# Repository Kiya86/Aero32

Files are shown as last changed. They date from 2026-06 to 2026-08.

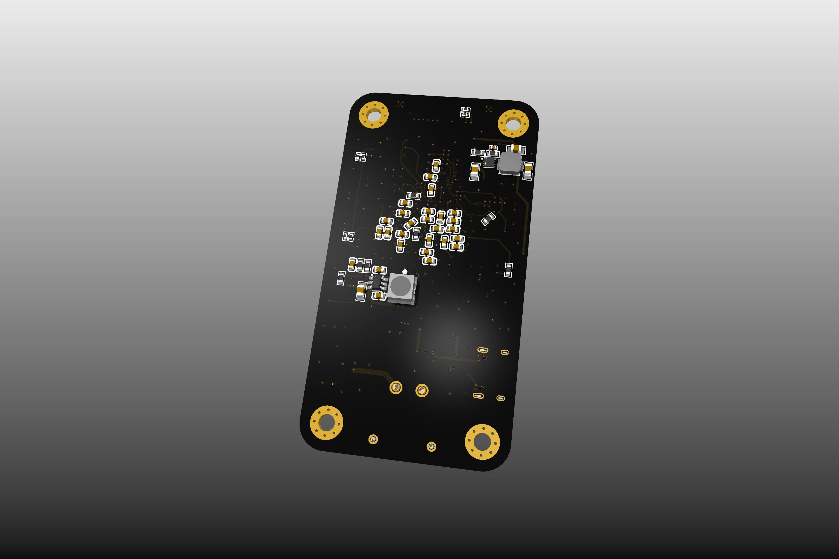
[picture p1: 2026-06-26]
Photos/BoardRender2.jpg

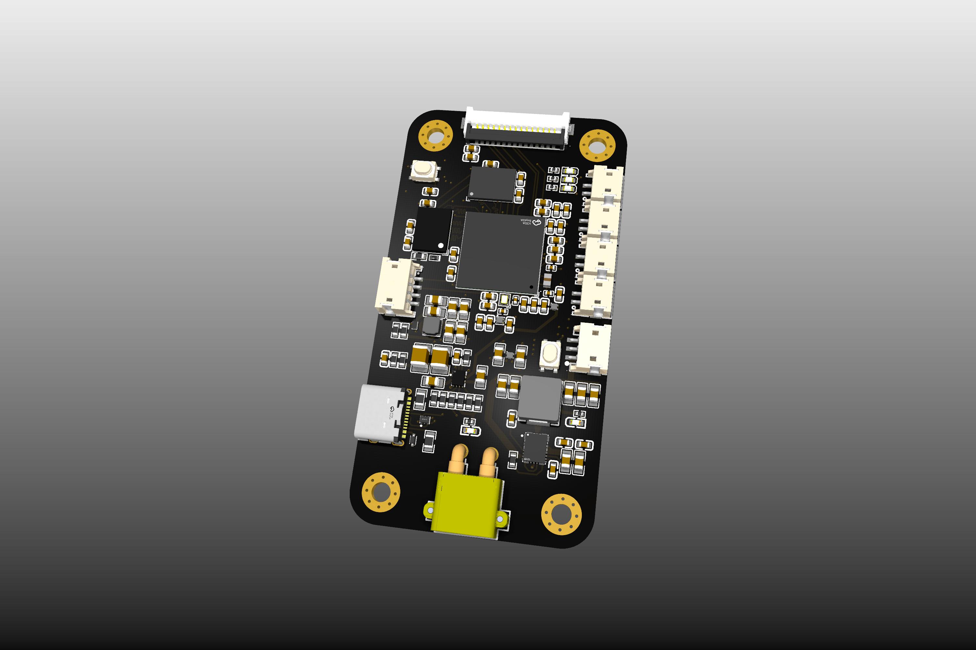
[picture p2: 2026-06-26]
Photos/BoardRender1.jpg

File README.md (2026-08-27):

# Aero32

MainRender1
BoardRender1

<h4 align="center">
A custom STM32N6-based AI vision module!
</h4>

<div align="center">





</div>

<p align="center">
  <a href="#key-features">Key Features</a> •
  <a href="#purpose">Purpose</a> •
  <a href="#pcb">PCB</a> •
  <a href="#main-components">Main Components</a> •
  <a href="#communication-interfaces">Communication Interfaces</a> •
  <a href="#power-architecture">Power System</a> •
  <a href="#bom">BOM</a> 
</p>

## Key Features

- **STM32N657X0H3Q** - Neural-ART accelerator that is used alongside the STM32N6 MCU
- **15-Pin CSI FPC Connector** - Camera sensor interface
- **MT35XU256ABA1G12** - 256 Mbit Octal SPI NOR Flash for either firmware or data 
- **IS66WVO32M8DALL** - 256 Mbit PSRAM for working memory
- **2× UART Ports** - Serial breakout headers
- **2× I2C Ports** - Two-wire serial communication breakout headers
- **1× SPI Port** - High-speed peripheral interface breakout
- **48 MHz & 32.768 kHz Crystals** - System clock and low power RTC
- **XT30 Battery Input** - 3S–4S LiPo input
- **5× Status LEDs** - 3 green + 2 red for power and debug feedback
- **Input OR** - TPS2121 power multiplexer for safe dual-source power switching

## Purpose

Aero32 is a small and compact AI vision board designed to serve as a node for drones or other flight hardware. The board offloads computer vision and processing from the external processing, communicating the results over UART, I2C, or SPI.

The STM32N6's Neural Processing Unit (NPU) allows anomaly detection, human recognition, and other advanced recognition directly on the board without AI hardware or wifi.

## PCB

Designed in **KiCad** and manufactured through **JLCPCB** (soon). The board uses a **6-layer PCB stackup** to allow for a reduction of EMI and signal interference. 

### Schematic

Aero32-1

## Main Components

| Category | Component | Description |
|---|---|---|
| Microcontroller | STM32N657X0H3Q | STM32N6 with NPU |
| NOR Flash | MT35XU256ABA1G12-0AUT | 256 Mbit Octal SPI Flash (Micron) |
| PSRAM | IS66WVO32M8DALL-200BLI | 256 Mbit Pseudo-SRAM (ISSI) |
| Camera Connector | XF3M(1)-1515-1B | 15-Pin 1mm Pitch FPC (Omron) |
| Main Buck Regulator | LM61495Q5RPHRQ1 | 3–36V 10A Automotive Buck (TI) |
| Aux Buck (3A) | AP3441LSHE-7B | 2.7–5.5V 3A Adjustable Buck |
| Aux Buck (3A) | TPS62088YFPR | 2.4–5.5V 3A Adjustable Buck (TI) |
| Fixed 3.3V Buck | TPS560430X3FDBVR | 4–36V 600mA 3.3V Fixed Buck (TI) |
| 1.8V LDO (×2) | ETA5055V180DD1E | 1.8V 500mA LDO |
| 3.3V LDO | ETA5055V330DD1E | 3.3V 500mA LDO |
| Power Mux | TPS2121RUXR | ORing Power Multiplexer (TI) |
| USB ESD | TPD2E001DRYR | 2-Channel USB ESD Protection (TI) |
| USB Connector | HC-TYPE-C-16P-01A-G | USB Type-C 16P 3A Female |
| Power Input | XT30PW-M | XT30 Male 15A Connector |
| System Crystal | SX0B48.000F0810F30 | 48 MHz ±10ppm Crystal |
| RTC Crystal | NX2012SA 32.768K | 32.768 kHz ±20ppm Crystal |
| Boot / Reset | K2-1808SN-A4SW | SPST Tactile Switch (×2) |
| Status LEDs | KT-0603G / KT-0603R | Green (×3) / Red (×2) 0603 LEDs |
| TVS Diode | LESD5D5.0CT1G | 150W Bidirectional TVS 5V |

## Communication Interfaces

### UART (×2)
Two independent UART breakout ports via 2-pin JST ZH 1.5mm connectors.

### I2C (×2)
Two I2C ports broken out via JST ZH 1.5mm connectors.

### SPI (×1)
One SPI port available for high-speed peripheral communication.

### Camera (CSI)
A 15-pin 1mm pitch FPC connector (Omron XF3M) provides the camera sensor interface.

## Power Architecture

Aero32 supports dual power inputs (USB-C and XT30 battery) with automatic source switching via the TPS2121 power mux.

## BOM

The full Bill of Materials is available in [`Aero32_BOM.csv`](./PCB/Aero32_BOM.csv), formatted for direct JLCPCB assembly upload.

JLCPCB Quote


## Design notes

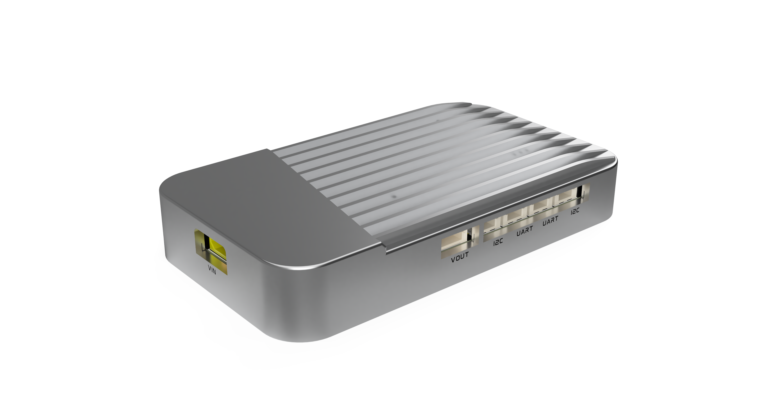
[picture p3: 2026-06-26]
Photos/MainRender3.png

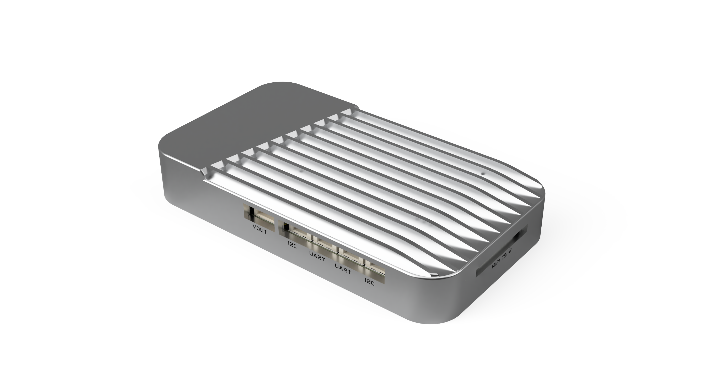
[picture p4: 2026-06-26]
Photos/MainRender1.png

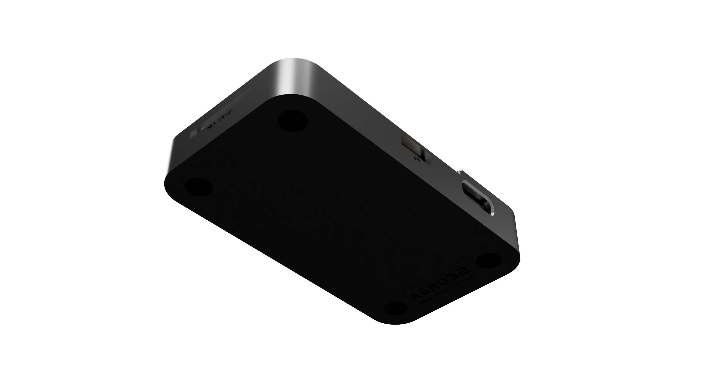
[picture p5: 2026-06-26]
Photos/MainRender2.png

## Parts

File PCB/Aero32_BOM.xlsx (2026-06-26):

Comment | Designator | Footprint | JLCPCB Part #（optional）
100nF | C19, C27, C29, C36, C37, C44, C46, C53, C54, C55, C57, C58, C60, C61, C62, C64, C65, C67, C68, C69, C71, C73, C74, C77, C78, C79, C81, C82, C83, C84, C86, C87, C88, C90, C91, C92 | C0603 | C45000
1uF | C1, C3, C10, C13, C14, C16, C17, C35, C48, C56, C59, C63, C66, C70, C72, C75, C76, C80, C85, C89, C93, C94 | C0603 | C1592
22uF | C18, C21, C22, C23, C25, C26, C30, C31, C34, C38, C40, C43, C47 | C0805 | C76634
10uF | C2, C4, C5, C6, C9, C11, C12, C15 | C0805 | C440198
470nF | C7, C8 | C0603 | C513577
47uF | C24, C28 | C1210 | C84494
8.2pF | C49, C52 | C0402 | C260529
2.2pF | C50, C51 | C0402 | C88887
22pF | C33 | C0402 | C1555
4.7uF | C41 | C0603 | C1705
2.2uF | C45 | C0603 | C1607
10kΩ | R2, R4, R6, R34 | R0603 | C25804
10kΩ | R14, R16, R27, R30 | R0603 | C25804
1.5kΩ | R21, R22, R24, R25 | R0402 | C25867
100kΩ | R12, R13, R37 | R0603 | C14675
68Ω | R31, R33, R36 | R0402 | C25178
47kΩ | R3, R5 | R0603 | C25819
5.1kΩ | R7, R8 | R0805 | C269748
2.2kΩ | R23, R26 | R0402 | C25879
200Ω | R28, R29 | R0603 | C8218
1kΩ | R32, R35 | R0402 | C11702
27kΩ | R1 | R0603 | C22967
56.2kΩ | R9 | R0603 | C23080
115kΩ | R10 | R0603 | C22783
18.7kΩ | R11 | R0603 | C22893
150kΩ | R15 | R0603 | C22807
91kΩ | R19 | R0603 | C23265
20kΩ | R20 | R0603 | C4184
240nH | L1 | IND-SMD_L3.0-W3.0_MAI3015S | C520265
2.7uH | L2 | IND-SMD_DH0630H-1R5M | C41407066
2.2uH | L4 | IND-SMD_L4.5-W4.1_GSSM0420 | C22463806
12uH | L5 | IND-SMD_L4.8-W4.8 | C22385343
TVS | D1 | SOD-523_L1.2-W0.8-LS1.6-BI | C383211
Diode | D2 | DSN2_L1.0-W0.6-RD | C604339
ETA5055V180DD1E | U1, U3 | DFN-4_L1.0-W1.0-P0.65-BL-EP | C5776774
ETA5055V330DD1E | U2 | XDFN-4_L1.0-W1.0-P0.65-BL-EP | C22466949
TPS62088YFPR | U4 | DSBGA-6_L0.8-W1.2-P0.40-R3-C2-TL | C575572
TPD2E001DRYR | U5 | SON-6_L1.5-W1.0-P0.50-BL | C379992
TPS2121RUXR | U6 | VQFN-HR-12_L2.5-W2.0-P0.50-BL | C485916
LM61495Q5RPHRQ1_C3188409 | U7 | VQFN-16_L4.5-W3.5-P0.50-TL_TI_RPH | C3188409
AP3441LSHE-7B | U9 | DFN-8_L2.0-W2.0-P0.50-BL-EP1.7 | C2072094
TPS560430X3FDBVR | U10 | SOT-23-6_L2.9-W1.6-P0.95-LS2.8-BR | C2071721
STM32N657X0H3Q | U11 | BGA-264_L14.0-W14.0-STM32N657X0H3Q | C42418080
MT35XU256ABA1G12-0AUT | U12 | T-PBGA-24_L8.0-W6.0-P1.00-TL_MICRON_12 | C7235747
IS66WVO32M8DALL-200BLI | U13 | TFBGA-24_L8.0-W6.0-P1.00-TL_MX25UW25645GXDI00 | C17535354
32.768kHz | X1 | XTAL_NX2012SA_NDK | C500343
48MHz | X2 | CRYSTAL-SMD_4P-L1.6-W1.2-BL | C7301928
K2-1808SN-A4SW | SW1, SW2 | KEY-SMD_4P-L4.2-W3.2-P2.20-LS5.1-TL | C92589
JST | CN2, CN3, CN4, CN5 | CONN-SMD_S2B-ZR-SM4A | C265329
KT-0603G | LED1, LED3, LED5 | LED0603-RD | C12624
KT-0603R | LED2, LED4 | LED-SMD_L1.6-W0.8-R-RD | C2286
XT30PW-M | CN1 | CONN-TH_XT30PW-M | C431092
JST | CN6 | CONN-TH_S3B-ZR-SM4A-TF-LF-SN | C72591
JST | CN7 | CONN-SMD_4P-P1.50_S4B-ZR-SM4A-TF-LF-SN | C485354
XF3M | FPC1 | FPC-SMD_XF3M-1-1515-1B | C6036307
HC-TYPE-C-16P-01A-G | USB1 | USB-C-SMD_G-SWITCH_GT-USB-7010EN | C2997435

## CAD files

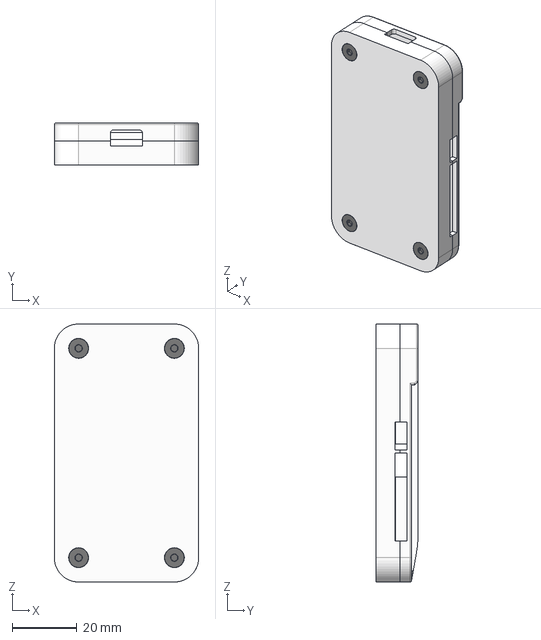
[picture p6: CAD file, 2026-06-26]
CAD/Aero32 - Housing.step
44.5 x 13.0 x 79.5 mm

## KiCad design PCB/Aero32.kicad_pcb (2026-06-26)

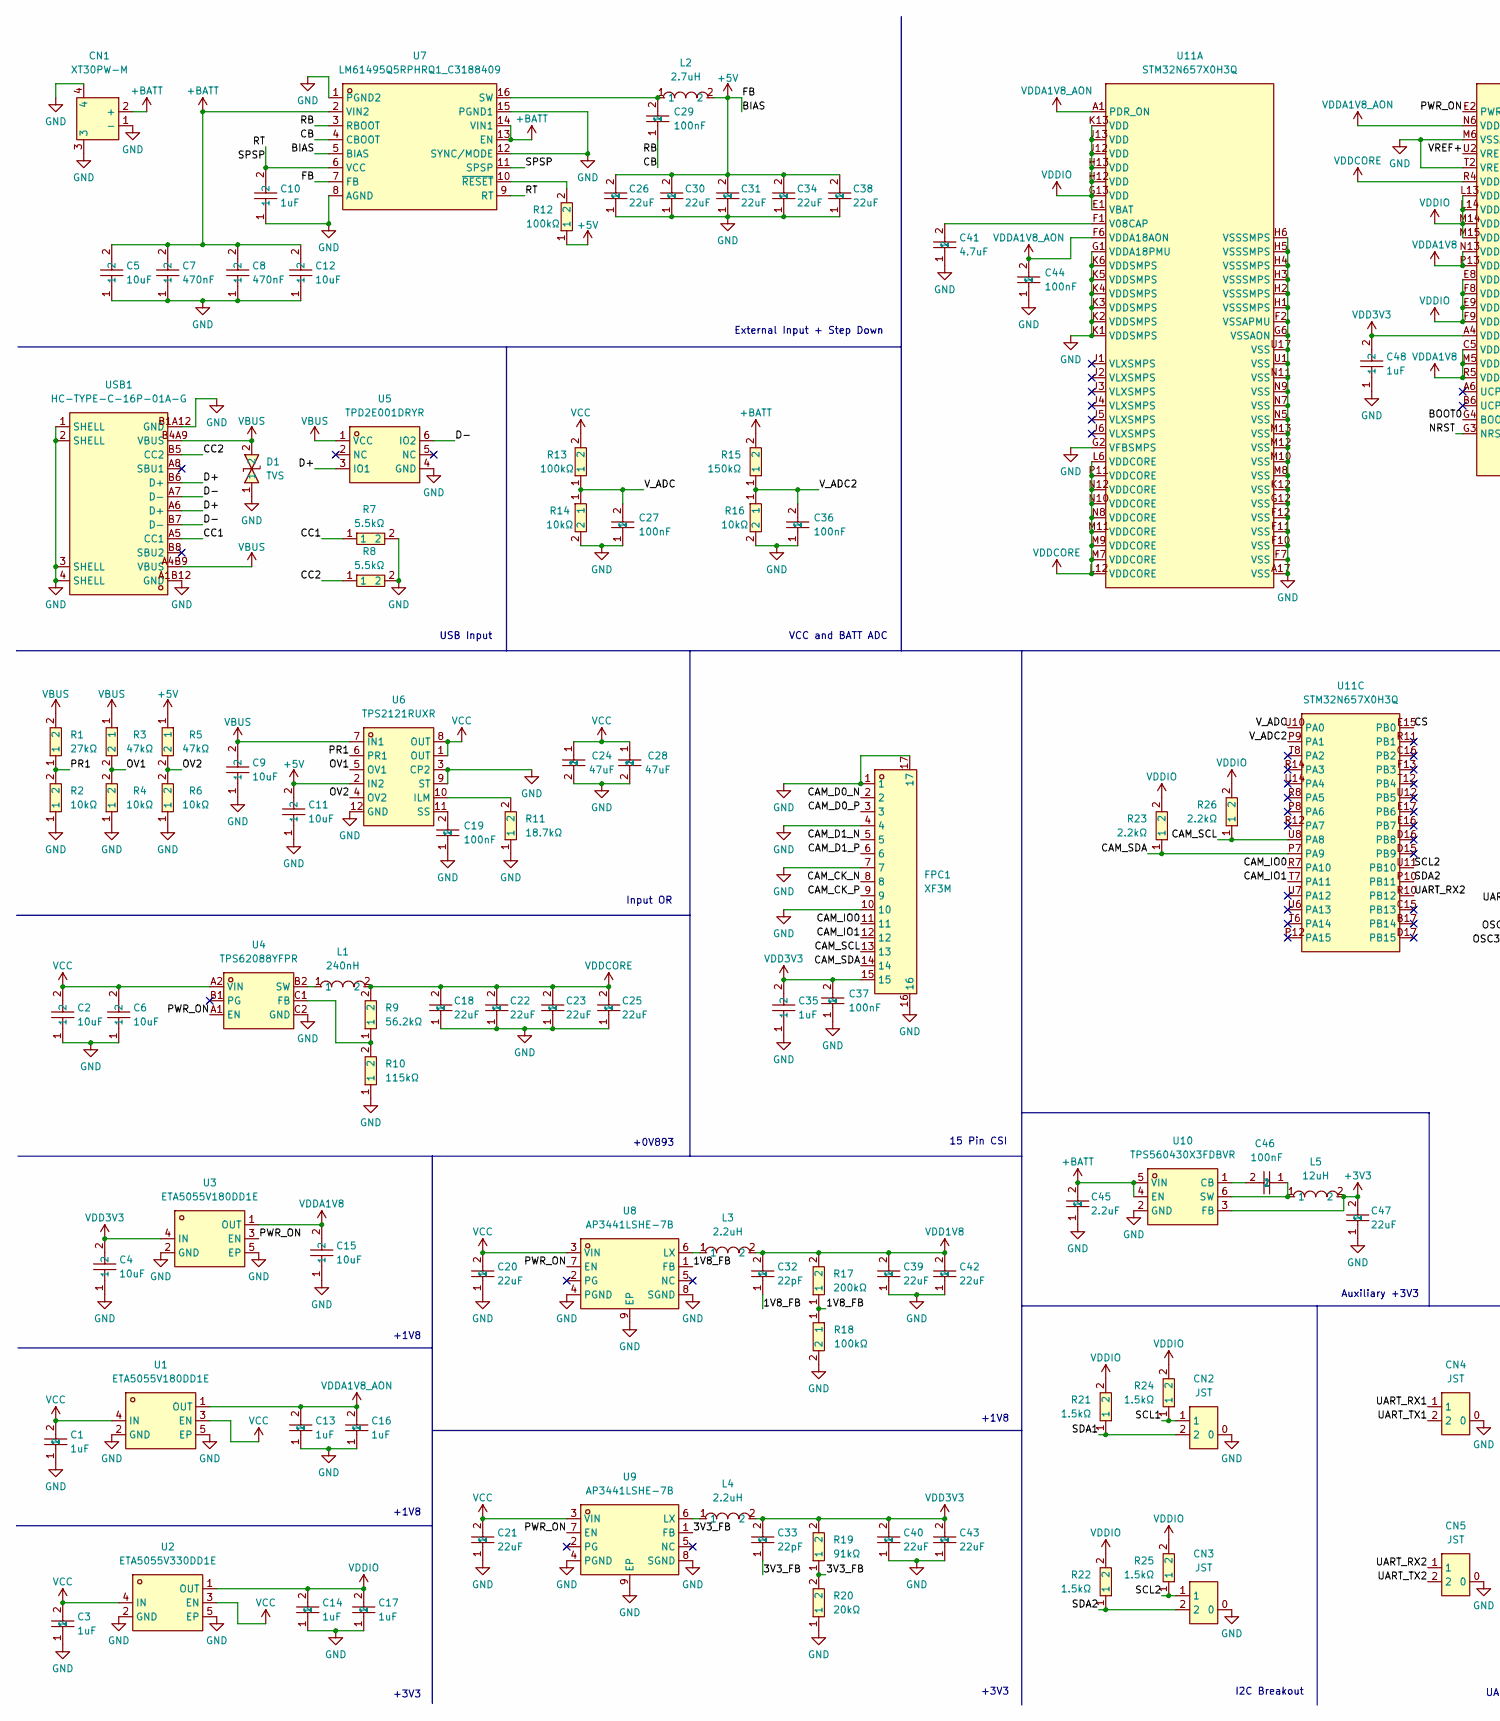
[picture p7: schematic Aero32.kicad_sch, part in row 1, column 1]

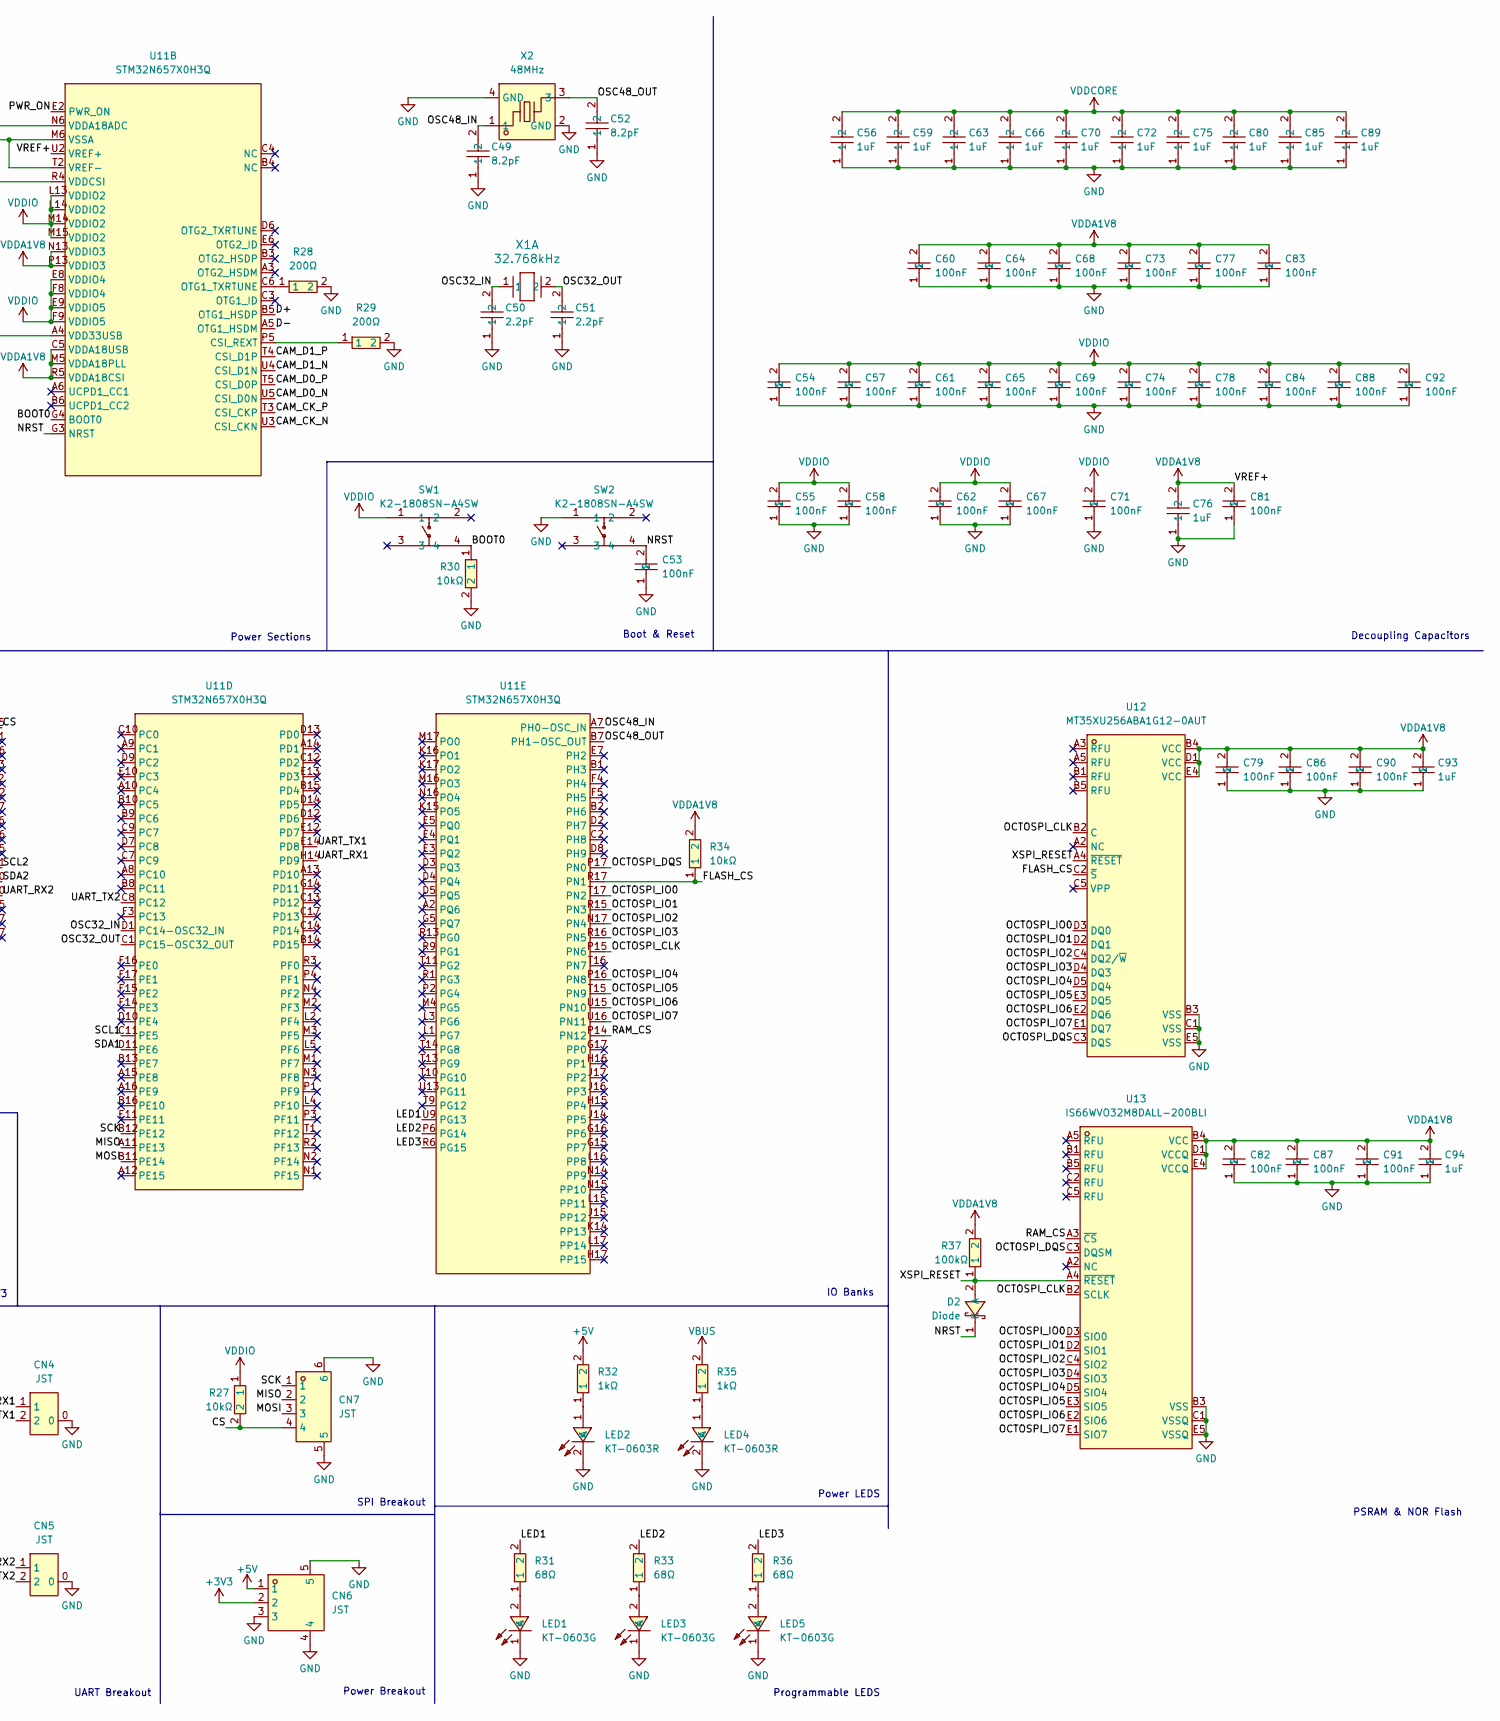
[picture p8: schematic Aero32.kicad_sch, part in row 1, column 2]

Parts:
C1, C3, C13, C14, C16, C17, C93, C94: 1uF; C0603; MPN CL10A105KO8NNNC; LCSC Part C1592
C2, C4, C5, C6, C9, C11, C12, C15: 10uF; C0805; MPN GRM21BR61H106KE43L; LCSC Part C440198
C7, C8: 470nF; C0603; MPN CC0603KRX7R9BB474; LCSC Part C513577
C10, C35, C48, C56, C59, C63, C66, C70, C72, C75, C76, C80, C85, C89: 1uF; C0603; MPN CL10A105KB8NNNC; LCSC Part C15849
C18, C20, C21, C22, C23, C25, C26, C30, C31, C34, C38, C39, C40, C42, C43, C47: 22uF; C0805; MPN C2012X5R1A226KT000N; LCSC Part C76634
C19, C27, C29, C36, C37, C44, C46, C53, C54, C55, C57, C58, C60, C61, C62, C64, C65, C67, C68, C69, C71, C73, C74, C77, C78, C79, C81, C82, C83, C84, C86, C87, C88, C90, C91, C92: 100nF; C0603; MPN GRM188R71C104KA01D; LCSC Part C45000
C24, C28: 47uF; C1210; MPN GRM32ER71A476KE15L; LCSC Part C84494
C32, C33: 22pF; C0402; MPN 0402CG220J500NT; LCSC Part C1555
C41: 4.7uF; C0603; MPN CL10A475KP8NNNC; LCSC Part C1705
C45: 2.2uF; C0603; MPN CL10A225KP8NNNC; LCSC Part C1607
C49, C52: 8.2pF; C0402; MPN CC0402CRNPO9BN8R2; LCSC Part C260529
C50, C51: 2.2pF; C0402; MPN GJM1555C1H2R2WB01D; LCSC Part C88887
CN1: XT30PW-M; CONN-TH_XT30PW-M; MPN XT30PW-M30.G.Y; LCSC Part C431092
CN2, CN3, CN4, CN5: JST; CONN-SMD_S2B-ZR-SM4A; MPN S2B-ZR-SM4A-TF(LF)(SN); LCSC Part C265329
CN6: JST; CONN-TH_S3B-ZR-SM4A-TF-LF-SN; MPN S3B-ZR-SM4A-TF(LF)(SN); LCSC Part C72591
CN7: JST; CONN-SMD_4P-P1.50_S4B-ZR-SM4A-TF-LF-SN; MPN S4B-ZR-SM4A-TF(LF)(SN); LCSC Part C485354
D1: TVS; SOD-523_L1.2-W0.8-LS1.6-BI; MPN LESD5D5.0CT1G; LCSC Part C383211
D2: Diode; DSN2_L1.0-W0.6-RD; MPN NSR05F30NXT5G; LCSC Part C604339
FPC1: XF3M; FPC-SMD_XF3M-1-1515-1B; MPN XF3M(1)-1515-1B; LCSC Part C6036307
L1: 240nH; IND-SMD_L3.0-W3.0_MAI3015S; MPN MAI3015S-R24MT; LCSC Part C520265
L2: 2.7uH; IND-SMD_DH0630H-1R5M; MPN DH0630H-2R7M; LCSC Part C41407066
L3, L4: 2.2uH; IND-SMD_L4.5-W4.1_GSSM0420; MPN SL0420-2R2M; LCSC Part C22463806
L5: 12uH; IND-SMD_L4.8-W4.8; MPN LPS5030-123MRC; LCSC Part C22385343
LED1, LED3, LED5: KT-0603G; LED0603-RD; MPN KT-0603G; LCSC Part C12624
LED2, LED4: KT-0603R; LED-SMD_L1.6-W0.8-R-RD; MPN KT-0603R; LCSC Part C2286
R1: 27kΩ; R0603; MPN 0603WAF2702T5E; LCSC Part C22967
R2, R4, R6, R34: 10kΩ; R0603; MPN 0603WAF1002T5E; LCSC Part C25804
R3, R5: 47kΩ; R0603; MPN 0603WAF4702T5E; LCSC Part C25819
R7, R8: 5.5kΩ; R0805; MPN RMC08055.1K1%N; LCSC Part C269748
R9: 56.2kΩ; R0603; MPN 0603WAF5622T5E; LCSC Part C23080
R10: 115kΩ; R0603; MPN 0603WAF1153T5E; LCSC Part C22783
R11: 18.7kΩ; R0603; MPN 0603WAF1872T5E; LCSC Part C22893
R12, R13, R18, R37: 100kΩ; R0603; MPN RC0603FR-07100KL; LCSC Part C14675
R14, R16, R27, R30: 10kΩ; R0603; MPN 0603WAJ0103T5E; LCSC Part C15401
R15: 150kΩ; R0603; MPN 0603WAF1503T5E; LCSC Part C22807
R17: 200kΩ; R0603; MPN 0603WAF2003T5E; LCSC Part C25811
R19: 91kΩ; R0603; MPN 0603WAF9102T5E; LCSC Part C23265
R20: 20kΩ; R0603; MPN 0603WAF2002T5E; LCSC Part C4184
R21, R22, R24, R25: 1.5kΩ; R0402; MPN 0402WGF1501TCE; LCSC Part C25867
R23, R26: 2.2kΩ; R0402; MPN 0402WGF2201TCE; LCSC Part C25879
R28, R29: 200Ω; R0603; MPN 0603WAF2000T5E; LCSC Part C8218
R31, R33, R36: 68Ω; R0402; MPN 0402WGJ0680TCE; LCSC Part C25178
R32, R35: 1kΩ; R0402; MPN 0402WGF1001TCE; LCSC Part C11702
SW1, SW2: K2-1808SN-A4SW; KEY-SMD_4P-L4.2-W3.2-P2.20-LS5.1-TL; MPN K2-1808SN-A4SW-01; LCSC Part C92589
U1, U3: ETA5055V180DD1E; DFN-4_L1.0-W1.0-P0.65-BL-EP; MPN ETA5055V180DD1E; LCSC Part C5776774
U2: ETA5055V330DD1E; XDFN-4_L1.0-W1.0-P0.65-BL-EP; MPN ETA5055V330DD1E; LCSC Part C22466949
U4: TPS62088YFPR; DSBGA-6_L0.8-W1.2-P0.40-R3-C2-TL; MPN TPS62088YFPR; LCSC Part C575572
U5: TPD2E001DRYR; SON-6_L1.5-W1.0-P0.50-BL; MPN TPD2E001DRYR; LCSC Part C379992
U6: TPS2121RUXR; VQFN-HR-12_L2.5-W2.0-P0.50-BL; MPN TPS2121RUXR; LCSC Part C485916
U7: LM61495Q5RPHRQ1_C3188409; VQFN-16_L4.5-W3.5-P0.50-TL_TI_RPH; MPN LM61495Q5RPHRQ1; LCSC Part C3188409
U8, U9: AP3441LSHE-7B; DFN-8_L2.0-W2.0-P0.50-BL-EP1.7; MPN AP3441LSHE-7B; LCSC Part C2072094
U10: TPS560430X3FDBVR; SOT-23-6_L2.9-W1.6-P0.95-LS2.8-BR; MPN TPS560430X3FDBVR; LCSC Part C2071721
U11: STM32N657X0H3Q; BGA-264_L14.0-W14.0-STM32N657X0H3Q; MPN STM32N657X0H3Q; LCSC Part C42418080
U12: MT35XU256ABA1G12-0AUT; T-PBGA-24_L8.0-W6.0-P1.00-TL_MICRON_12; MPN MT35XU256ABA1G12-0AUT; LCSC Part C7235747
U13: IS66WVO32M8DALL-200BLI; TFBGA-24_L8.0-W6.0-P1.00-TL_MX25UW25645GXDI00; MPN IS66WVO32M8DALL-200BLI; LCSC Part C17535354
USB1: HC-TYPE-C-16P-01A-G; USB-C-SMD_G-SWITCH_GT-USB-7010EN; MPN HC-TYPE-C-16P-01A-G; LCSC Part C2997435
X1: 32.768kHz; XTAL_NX2012SA_NDK
X2: 48MHz; CRYSTAL-SMD_4P-L1.6-W1.2-BL; MPN SX0B48.000F0810F30; LCSC Part C7301928

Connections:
+3V3: C47.2, CN6.2, L5.2, U10.3 (FB)
+5V: C11.2, C26.2, C30.2, C31.2, C34.2, C38.2, CN6.1, L2.2, R5.1, R12.1, R32.2, U6.2 (IN2), U7.5 (BIAS), U7.7 (FB)
+BATT: C5.2, C7.2, C8.2, C12.2, C45.2, CN1.2 (+), R15.2, U7.2 (VIN2), U7.13 (EN), U7.14 (VIN1), U10.4 (EN), U10.5 (VIN)
/3V3_FB: C33.1, R19.1, R20.2, U9.1 (FB)
/BOOT0: R30.1, SW1.4, U11.G4 (BOOT0)
/CAM_CK_N: FPC1.8, U11.U3 (CSI_CKN)
/CAM_CK_P: FPC1.9, U11.T3 (CSI_CKP)
/CAM_D0_N: FPC1.2, U11.U5 (CSI_D0N)
/CAM_D0_P: FPC1.3, U11.T5 (CSI_D0P)
/CAM_D1_N: FPC1.5, U11.U4 (CSI_D1N)
/CAM_D1_P: FPC1.6, U11.T4 (CSI_D1P)
/CAM_IO0: FPC1.11, U11.R7 (PA10)
/CAM_IO1: FPC1.12, U11.T7 (PA11)
/CAM_SCL: FPC1.13, R26.1, U11.U8 (PA8)
/CAM_SDA: FPC1.14, R23.1, U11.P7 (PA9)
/CB: C29.1, U7.3 (RBOOT), U7.4 (CBOOT)
/CC1: R7.1, USB1.A5 (CC1)
/CC2: R8.1, USB1.B5 (CC2)
/CS: CN7.4, R27.2, U11.E15 (PB0)
/D+: U5.3 (IO1), U11.B5 (OTG1_HSDP), USB1.A6 (D+), USB1.B6 (D+)
/D-: U5.6 (IO2), U11.A5 (OTG1_HSDM), USB1.A7 (D-), USB1.B7 (D-)
/FLASH_CS: R34.1, U11.R17 (PN1), U12.C2 (~S)
/LED1: R31.2, U11.U9 (PG13)
/LED2: R33.2, U11.P6 (PG14)
/LED3: R36.2, U11.R6 (PG15)
/MISO: CN7.2, U11.A11 (PE13)
/MOSI: CN7.3, U11.B11 (PE14)
/NRST: C53.2, D2.1 (K), SW2.4, U11.G3 (NRST)
/OCTOSPI_CLK: U11.P15 (PN6), U12.B2 (C), U13.B2 (SCLK)
/OCTOSPI_DQS: U11.P17 (PN0), U12.C3 (DQS), U13.C3 (DQSM)
/OCTOSPI_IO0: U11.T17 (PN2), U12.D3 (DQ0), U13.D3 (SIO0)
/OCTOSPI_IO1: U11.R15 (PN3), U12.D2 (DQ1), U13.D2 (SIO1)
/OCTOSPI_IO2: U11.N17 (PN4), U12.C4 (DQ2/~W), U13.C4 (SIO2)
/OCTOSPI_IO3: U11.R16 (PN5), U12.D4 (DQ3), U13.D4 (SIO3)
/OCTOSPI_IO4: U11.P16 (PN8), U12.D5 (DQ4), U13.D5 (SIO4)
/OCTOSPI_IO5: U11.T15 (PN9), U12.E3 (DQ5), U13.E3 (SIO5)
/OCTOSPI_IO6: U11.U15 (PN10), U12.E2 (DQ6), U13.E2 (SIO6)
/OCTOSPI_IO7: U11.U16 (PN11), U12.E1 (DQ7), U13.E1 (SIO7)
/OSC32_IN: C50.2, U11.D1 (PC14-OSC32_IN), X1.1
/OSC32_OUT: C51.2, U11.C1 (PC15-OSC32_OUT), X1.2
/OSC48_IN: C49.2, U11.A7 (PH0-OSC_IN), X2.1
/OSC48_OUT: C52.2, U11.B7 (PH1-OSC_OUT), X2.3
/OV1: R3.2, R4.2, U6.5 (OV1)
/OV2: R5.2, R6.2, U6.4 (OV2)
/PR1: R1.1, R2.2, U6.6 (PR1)
/PWR_ON: U3.3 (EN), U4.A1 (EN), U8.7 (EN), U9.7 (EN), U11.E2 (PWR_ON)
/RAM_CS: U11.P14 (PN12), U13.A3 (~CS)
/RT: C10.2, U7.6 (VCC), U7.9 (RT), U7.11 (SPSP)
/SCK: CN7.1, U11.B12 (PE12)
/SCL1: CN2.1, R24.1, U11.C11 (PE5)
/SCL2: CN3.1, R25.1, U11.U11 (PB10)
/SDA1: CN2.2, R21.1, U11.D11 (PE6)
/SDA2: CN3.2, R22.1, U11.P10 (PB11)
/UART_RX1: CN4.1, U11.H14 (PD9)
/UART_RX2: CN5.1, U11.R10 (PB12)
/UART_TX1: CN4.2, U11.E14 (PD8)
/UART_TX2: CN5.2, U11.C8 (PC12)
/V_ADC: C27.2, R13.1, R14.1, U11.U10 (PA0)
/V_ADC2: C36.2, R15.1, R16.1, U11.P9 (PA1)
/XSPI_RESET: D2.2 (A), R37.1, U12.A4 (~RESET), U13.A4 (~RESET)
GND: C1.1, C2.1, C3.1, C4.1, C5.1, C6.1, C7.1, C8.1, C9.1, C10.1, C11.1, C12.1, C13.1, C14.1, C15.1, C16.1, C17.1, C18.1, C19.1, C20.1, C21.1, C22.1, C23.1, C24.2, C25.1, C26.1, C27.1, C28.2, C30.1, C31.1, C34.1, C35.1, C36.1, C37.1, C38.1, C39.1, C40.1, C41.1, C42.1, C43.1, C44.1, C45.1, C47.1, C48.1, C49.1, C50.1, C51.1, C52.1, C53.1, C54.1, C55.1, C56.1, C57.1, C58.1, C59.1, C60.1, C61.1, C62.1, C63.1, C64.1, C65.1, C66.1, C67.1, C68.1, C69.1, C70.1, C71.1, C72.1, C73.1, C74.1, C75.1, C76.1, C77.1, C78.1, C79.1, C80.1, C81.1, C82.1, C83.1, C84.1, C85.1, C86.1, C87.1, C88.1, C89.1, C90.1, C91.1, C92.1, C93.1, C94.1, CN1.1 (-), CN1.3, CN1.4, CN2.0, CN3.0, CN4.0, CN5.0, CN6.3, CN6.4, CN6.5, CN7.5, CN7.6, D1.1, FPC1.1, FPC1.4, FPC1.7, FPC1.10, FPC1.16, FPC1.17, LED1.1 (K), LED2.2 (K), LED3.1 (K), LED4.2 (K), LED5.1 (K), R2.1, R4.1, R6.1, R7.2, R8.2, R10.1, R11.1, R14.2, R16.2, R18.2, R20.1, R28.2, R29.2, R30.2, SW2.1, U1.2 (GND), U1.5 (EP), U2.2 (GND), U2.5 (EP), U3.2 (GND), U3.5 (EP), U4.C2 (GND), U5.4 (GND), U6.3 (CP2), U6.9 (ST), U6.12 (GND), U7.1 (PGND2), U7.8 (AGND), U7.12 (SYNC/MODE), U7.15 (PGND1), U8.4 (PGND), U8.8 (SGND), U8.9 (EP), U9.4 (PGND), U9.8 (SGND), U9.9 (EP), U10.2 (GND), U11.A17 (VSS), U11.F2 (VSSAPMU), U11.F7 (VSS), U11.F10 (VSS), U11.F11 (VSS), U11.F12 (VSS), U11.G1 (VDDA18PMU), U11.G2 (VFBSMPS), U11.G6 (VSSAON), U11.G12 (VSS), U11.H1 (VSSSMPS), U11.H2 (VSSSMPS), U11.H3 (VSSSMPS), U11.H4 (VSSSMPS), U11.H5 (VSSSMPS), U11.H6 (VSSSMPS), U11.K1 (VDDSMPS), U11.K2 (VDDSMPS), U11.K3 (VDDSMPS), U11.K4 (VDDSMPS), U11.K5 (VDDSMPS), U11.K6 (VDDSMPS), U11.K12 (VSS), U11.M6 (VSSA), U11.M8 (VSS), U11.M10 (VSS), U11.M12 (VSS), U11.M13 (VSS), U11.N5 (VSS), U11.N7 (VSS), U11.N9 (VSS), U11.N11 (VSS), U11.T2 (VREF-), U11.U1 (VSS), U11.U17 (VSS), U12.B3 (VSS), U12.C1 (VSS), U12.E5 (VSS), U13.B3 (VSS), U13.C1 (VSSQ), U13.E5 (VSSQ), USB1.1 (SHELL), USB1.2 (SHELL), USB1.3 (SHELL), USB1.4 (SHELL), USB1.A1B12 (GND), USB1.B1A12 (GND), X2.2 (GND), X2.4 (GND)
unnamed: C32.1, R17.1, R18.1, U8.1 (FB)
unnamed: C32.2, C39.2, C42.2, L3.2, R17.2
unnamed: L3.1, U8.6 (LX)
unnamed: LED1.2 (A), R31.1
unnamed: LED2.1 (A), R32.1
unnamed: LED3.2 (A), R33.1
unnamed: LED4.1 (A), R35.1
unnamed: LED5.2 (A), R36.1
unnamed: R9.1, R10.2, U4.C1 (FB)
unnamed: L1.1, U4.B2 (SW)
unnamed: R11.2, U6.10 (ILM)
unnamed: C19.2, U6.11 (SS)
unnamed: C29.2, L2.1, U7.16 (SW)
unnamed: R12.2, U7.10 (~RESET)
unnamed: L4.1, U9.6 (LX)
unnamed: C46.2, U10.1 (CB)
unnamed: C46.1, L5.1, U10.6 (SW)
unnamed: C41.2, U11.F1 (V08CAP)
unnamed: R29.1, U11.P5 (CSI_REXT)
unnamed: R28.1, U11.C6 (OTG1_TXRTUNE)
VBUS: C9.2, D1.2, R1.2, R3.1, R35.2, U5.1 (VCC), U6.7 (IN1), USB1.A4B9 (VBUS), USB1.B4A9 (VBUS)
VCC: C1.2, C2.2, C3.2, C6.2, C20.2, C21.2, C24.1, C28.1, R13.2, U1.3 (EN), U1.4 (IN), U2.3 (EN), U2.4 (IN), U4.A2 (VIN), U6.1 (OUT), U6.8 (OUT), U8.3 (VIN), U9.3 (VIN)
VDD3V3: C4.2, C33.2, C35.2, C37.2, C40.2, C43.2, C48.2, FPC1.15, L4.2, R19.2, U3.4 (IN), U11.A4 (VDD33USB)
VDDA1V8: C15.2, C60.2, C64.2, C68.2, C73.2, C76.2, C77.2, C79.2, C81.2, C82.2, C83.2, C86.2, C87.2, C90.2, C91.2, C93.2, C94.2, R34.2, R37.2, U3.1 (OUT), U11.C5 (VDDA18USB), U11.M5 (VDDA18PLL), U11.N13 (VDDIO3), U11.P13 (VDDIO3), U11.R5 (VDDA18CSI), U11.U2 (VREF+), U12.B4 (VCC), U12.D1 (VCC), U12.E4 (VCC), U13.B4 (VCC), U13.D1 (VCCQ), U13.E4 (VCCQ)
VDDA1V8_AON: C13.2, C16.2, C44.2, U1.1 (OUT), U11.A1 (PDR_ON), U11.F6 (VDDA18AON), U11.N6 (VDDA18ADC)
VDDCORE: C18.2, C22.2, C23.2, C25.2, C56.2, C59.2, C63.2, C66.2, C70.2, C72.2, C75.2, C80.2, C85.2, C89.2, L1.2, R9.2, U11.L6 (VDDCORE), U11.L12 (VDDCORE), U11.M7 (VDDCORE), U11.M9 (VDDCORE), U11.M11 (VDDCORE), U11.N8 (VDDCORE), U11.N10 (VDDCORE), U11.N12 (VDDCORE), U11.P11 (VDDCORE), U11.R4 (VDDCSI)
VDDIO: C14.2, C17.2, C54.2, C55.2, C57.2, C58.2, C61.2, C62.2, C65.2, C67.2, C69.2, C71.2, C74.2, C78.2, C84.2, C88.2, C92.2, R21.2, R22.2, R23.2, R24.2, R25.2, R26.2, R27.1, SW1.1, U2.1 (OUT), U11.E1 (VBAT), U11.E8 (VDDIO4), U11.E9 (VDDIO5), U11.F8 (VDDIO4), U11.F9 (VDDIO5), U11.G13 (VDD), U11.H12 (VDD), U11.H13 (VDD), U11.J12 (VDD), U11.J13 (VDD), U11.K13 (VDD), U11.L13 (VDDIO2), U11.L14 (VDDIO2), U11.M14 (VDDIO2), U11.M15 (VDDIO2)

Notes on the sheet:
+3V3
I2C Breakout
Power Sections
IO Banks
Input OR
Auxiliary +3V3
Power Breakout
UART Breakout
15 Pin CSI
USB Input
+1V8
External Input + Step Down
SPI Breakout
Power LEDS
PSRAM & NOR Flash
Programmable LEDS
+0V893
Decoupling Capacitors
VCC and BATT ADC
Boot & Reset

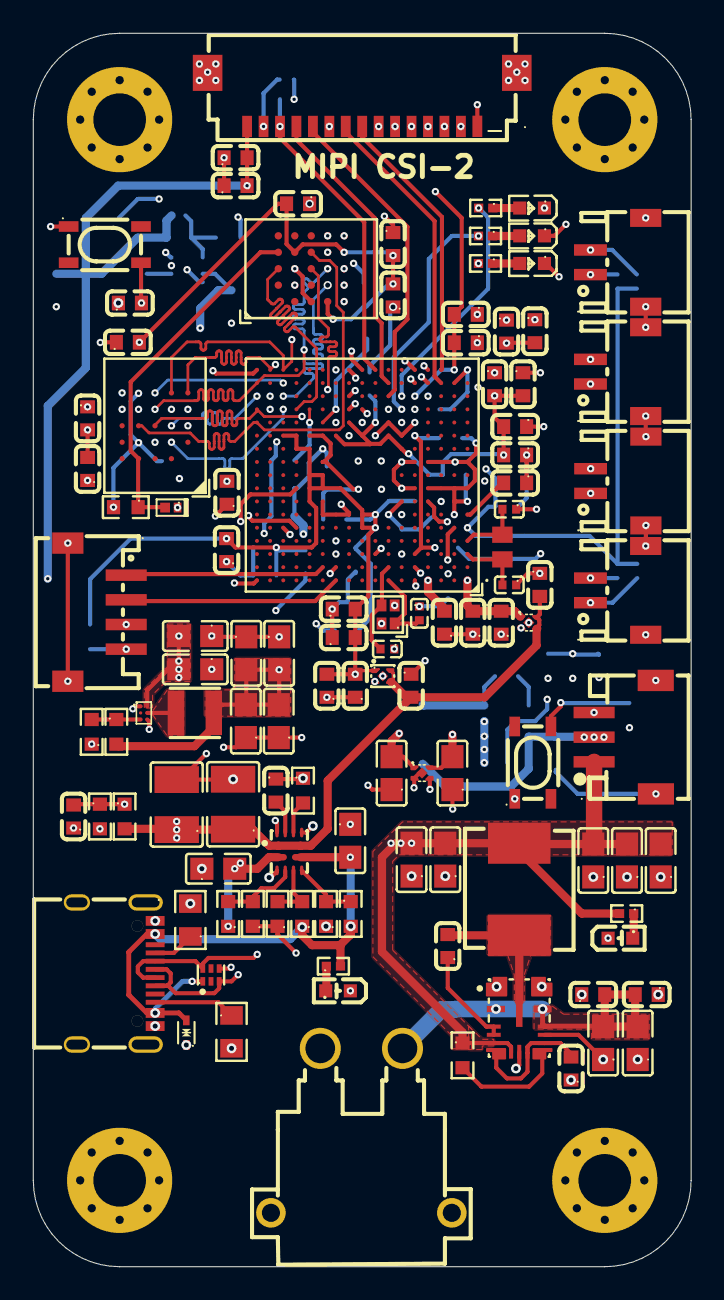
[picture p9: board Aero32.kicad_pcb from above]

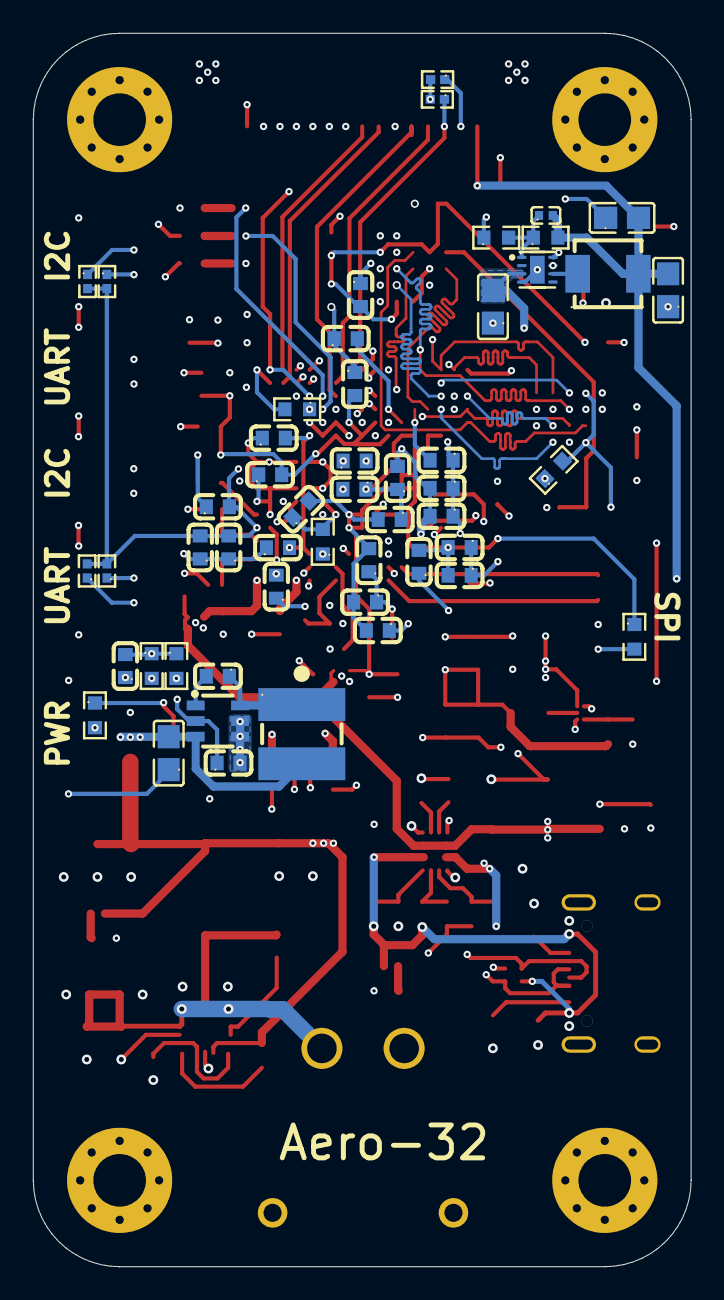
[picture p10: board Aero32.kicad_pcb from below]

Board: 6 copper layers, 40.0 x 75.0 mm, 161 parts (51 on the bottom side), 85 nets.

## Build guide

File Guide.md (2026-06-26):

# Aero32 (duh)

**hey. HEY.** this is not the Arduino tutorial you googled at 11pm.  

## Contents

- [Wait, What Even Is This?](#wait-what-even-is-this)

## Wait, What Even Is This?

Aero32 is a compact AI vision co-processor designed to plug into an existing flight computer via **UART, I2C, or SPI**. This is so that the flight computer doesn't have to do as much work. 

It runs an **STM32N6** which has a built-in Neural Processing Unit (NPU). This allows it to run object detection off-grid! 

Think of it like this:

```
┌─────────────────────────────────────────────┐
│                                             │
│   Flight Computer                           │
│   (busy doing important flight stuff)       │
│              │                              │
│              │  "hey what do you see?"      │
│              ▼                              │
│         [ AERO32 ]  ◄── camera              │
│      STM32N6 + NPU                          │
│      "I see a person / the ground /         │
│       something that shouldn't be there"    │
│                                             │
└─────────────────────────────────────────────┘
```
